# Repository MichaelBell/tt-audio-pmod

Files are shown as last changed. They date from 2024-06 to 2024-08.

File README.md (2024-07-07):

# Tiny Tapeout Audio Pmod

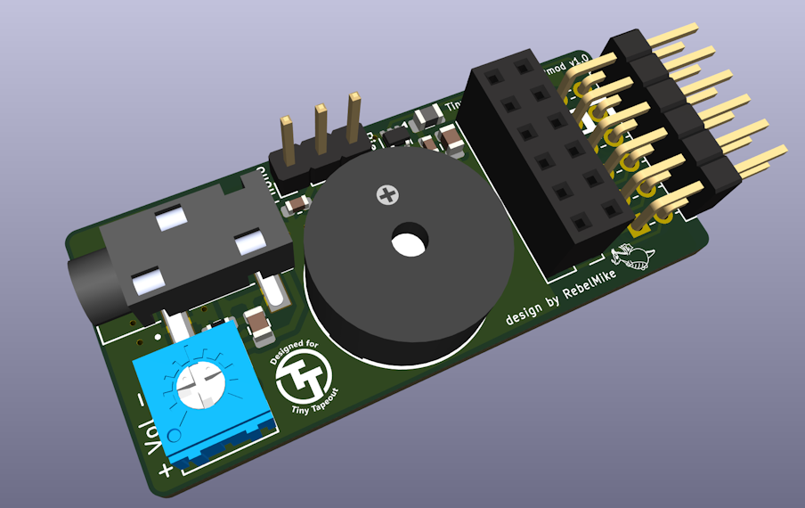
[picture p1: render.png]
Render of the Audio Pmod


This Pmod is designed to play mono PWM audio from out[7] or bidir[7], while allowing a second Pmod to be plugged in, passing through bidir[0-6] or out[0-6].  

The design has a low pass filter, to allow a large range of audio to be played the cutoff frequency is quite high.  It is therefore recommended that the PWM frequency is at least 200kHz to get good results.

If the piezo is selected with the jumper, it is driven after the low pass filter with no further filtering.

If the headphone jack is selected, AC coupling is applied to give a balanced signal.

The volume trim pot should be turned down to around 30-35 ohms to give nominal line level when the output is connected to a high impedance line in.  If using headphones with a low impedance it should be turned up towards the high end of the range (180-200 ohms).

IO 7 on the second Pmod is pulled high, which allows compatibility with the [QSPI Pmod](https://github.com/mole99/qspi-pmod).

The Pmod was designed in KiCad 8, here is the [schematic](tt-audio-pmod.pdf).

## Example Tiny Tapeout project

This [example project](https://github.com/MichaelBell/tt08-pwm-example) generates a PWM output sampling a sine wave of a configurable frequency.

## Simulation

The frequency response of the design was simulated in ltspice:

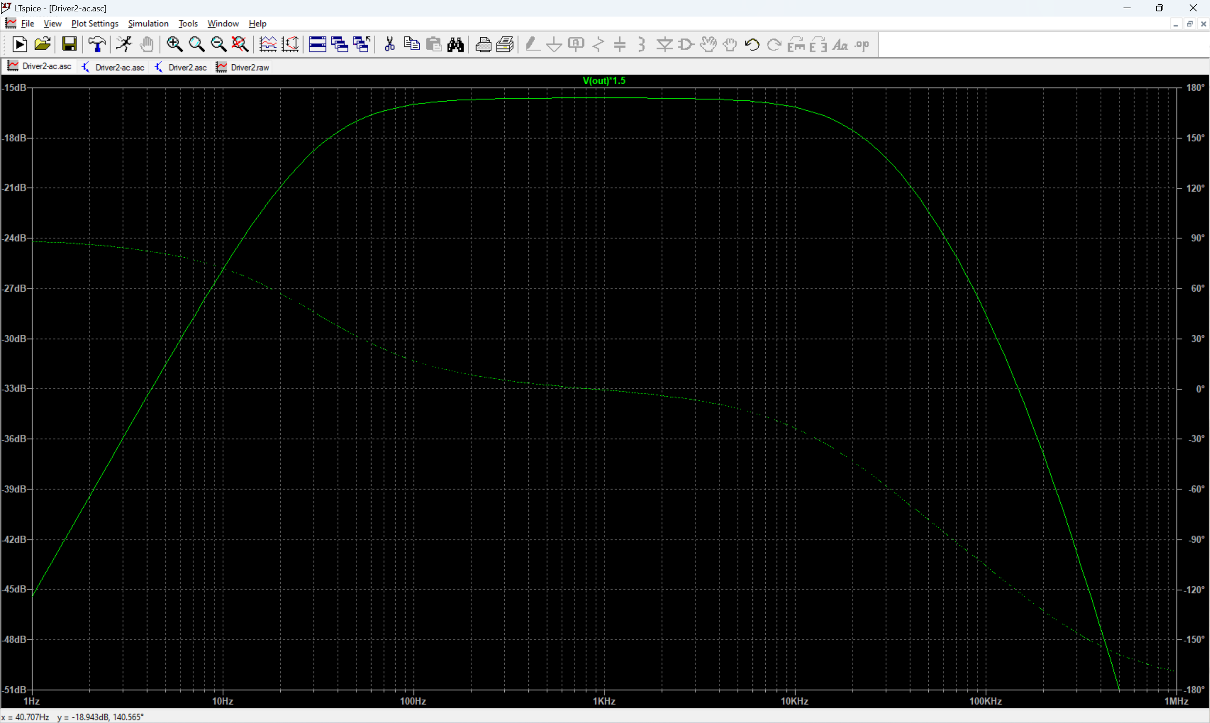
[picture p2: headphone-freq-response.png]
Frequency response with 17 ohm headphones


The ltspice simulations are in the [sim](sim/) directory.

## Testing

The first version of the Pmod is being manufactured and will be tested soon.

## Credits

Designed for Tiny Tapeout by RebelMike with the help of the excellent Tiny Tapeout Discord community.

   Copyright 2024 Mike Bell

   Licensed under the Apache License, Version 2.0 (the "License");
   you may not use this file except in compliance with the License.
   You may obtain a copy of the License at

   http://www.apache.org/licenses/LICENSE-2.0

   Unless required by applicable law or agreed to in writing, software
   distributed under the License is distributed on an "AS IS" BASIS,
   WITHOUT WARRANTIES OR CONDITIONS OF ANY KIND, either express or implied.
   See the License for the specific language governing permissions and
   limitations under the License.

Image on the reverse is by [ArtRose on Pixabay](https://pixabay.com/vectors/musical-notes-music-smile-merry-6159007/).  Used under the [Pixabay Content License](https://pixabay.com/service/license-summary/)

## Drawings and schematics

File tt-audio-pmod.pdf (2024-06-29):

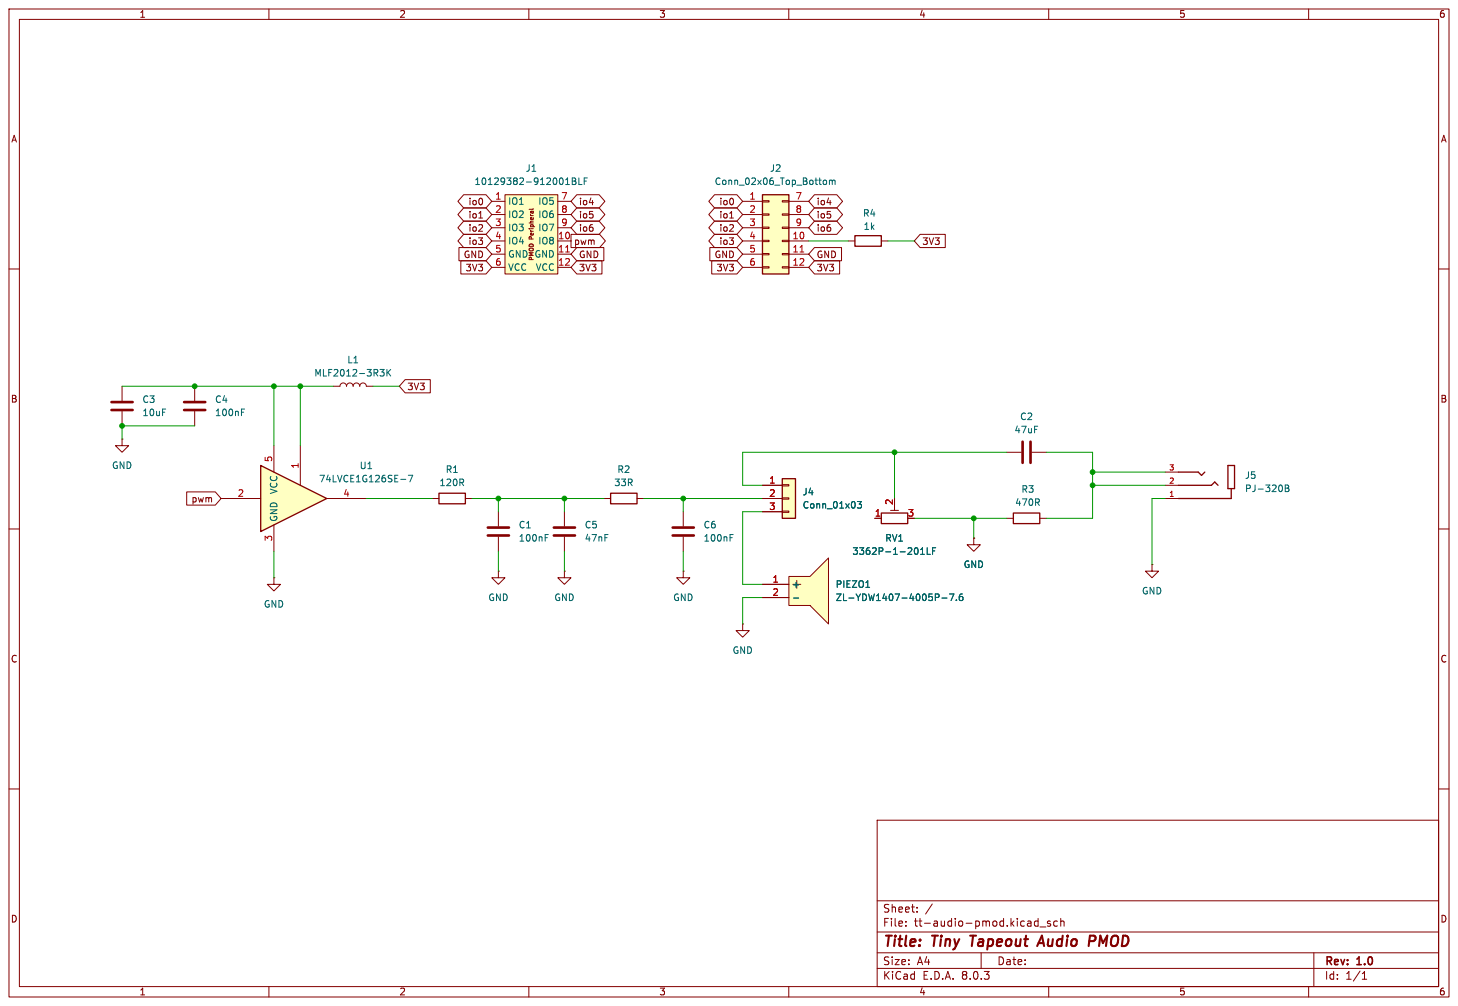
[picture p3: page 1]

File: tt-audio-pmod.kicad_sch Sheet: /
Id: 1/1 Title: Tiny Tapeout Audio PMOD

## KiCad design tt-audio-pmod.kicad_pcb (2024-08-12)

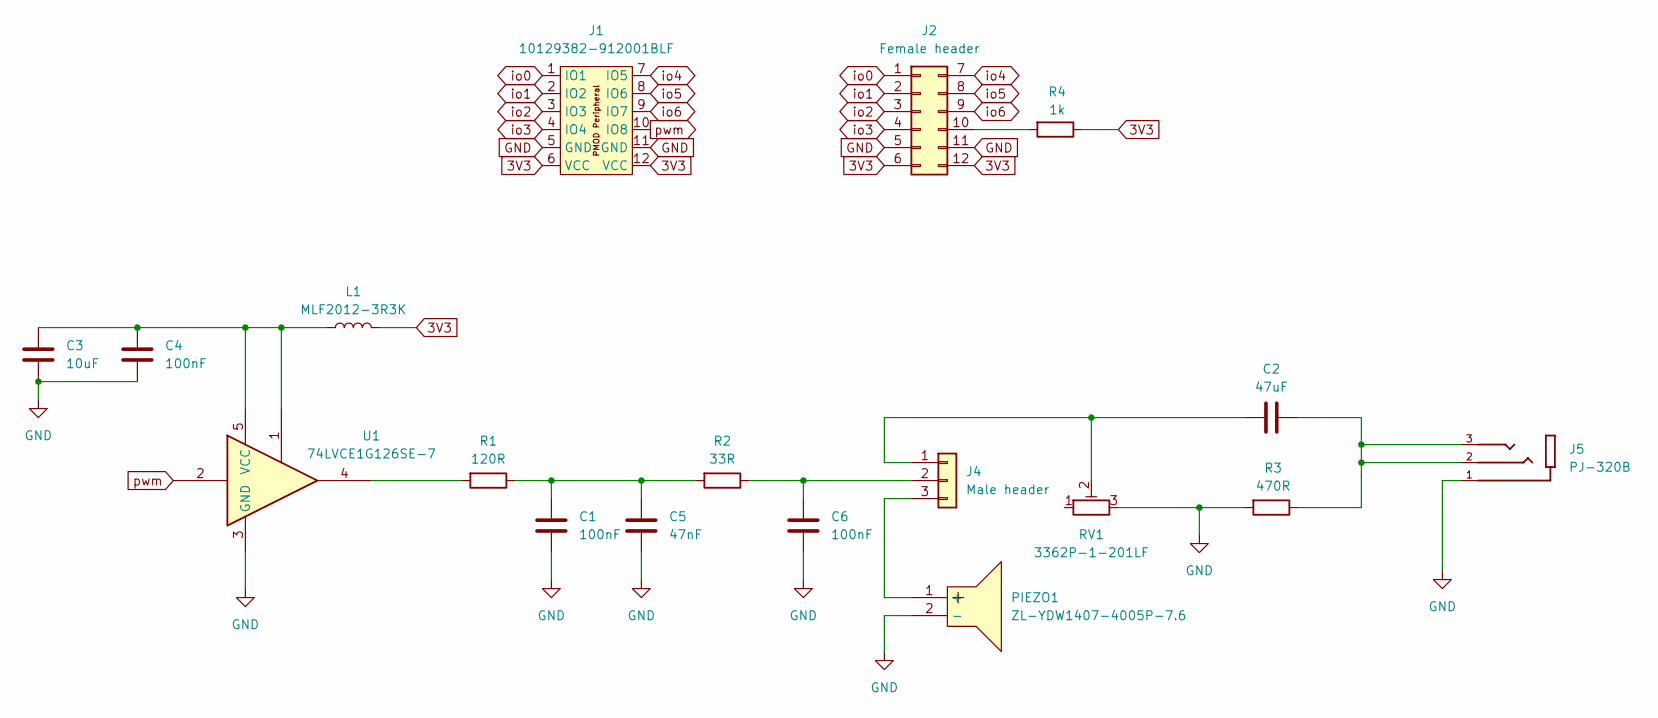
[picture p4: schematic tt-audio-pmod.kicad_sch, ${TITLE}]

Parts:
C1, C4, C6: 100nF; C_0603_1608Metric; LCSC Part C14663
C2: 47uF; C_0805_2012Metric; LCSC Part C16780
C3: 10uF; C_0805_2012Metric; LCSC Part C15850
C5: 47nF; C_0603_1608Metric; LCSC Part C1622
J1: 10129382-912001BLF; PinHeader_2x06_P2.54mm_PMODPeriph2B; LCSC Part C60565
J2: Female header; PinSocket_2x06_P2.54mm_Vertical_Column; LCSC Part C92269
J4: Male header; PinHeader_1x03_P2.54mm_Vertical; LCSC Part C49257
J5: PJ-320B; BOOMELE_PJ-320B; LCSC Part C2884998
L1: MLF2012-3R3K; L_0805_2012Metric; LCSC Part C2941578
PIEZO1: ZL-YDW1407-4005P-7.6; BUZ-TH_BD14.0-P7.60-D0.7-FD; LCSC Part C219740
R1: 120R; R_0603_1608Metric; LCSC Part C22787
R2: 33R; R_0603_1608Metric; LCSC Part C23140
R3: 470R; R_0603_1608Metric; LCSC Part C23179
R4: 1k; R_0603_1608Metric; LCSC Part C21190
RV1: 3362P-1-201LF; TRIM_3362P-1-102; LCSC Part C124581
U1: 74LVCE1G126SE-7; SOT-353_SC-70-5; LCSC Part C842506

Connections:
3V3: J1.6 (VCC), J1.12 (VCC), J2.6, J2.12, L1.2, R4.1
GND: C1.2, C3.2, C4.2, C5.2, C6.2, J1.5 (GND), J1.11 (GND), J2.5, J2.11, J5.1, PIEZO1.2 (-), R3.2, RV1.3, U1.3 (GND)
unnamed: C1.1, C5.1, R1.1, R2.2
unnamed: C2.1, J5.2, J5.3, R3.1
unnamed: J2.10, R4.2
unnamed: C2.2, J4.1, RV1.2
unnamed: C6.1, J4.2, R2.1
unnamed: J4.3, PIEZO1.1 (+)
unnamed: R1.2, U1.4
unnamed: C3.1, C4.1, L1.1, U1.1, U1.5 (VCC)
io0: J1.1 (IO1), J2.1
io1: J1.2 (IO2), J2.2
io2: J1.3 (IO3), J2.3
io3: J1.4 (IO4), J2.4
io4: J1.7 (IO5), J2.7
io5: J1.8 (IO6), J2.8
io6: J1.9 (IO7), J2.9
pwm: J1.10 (IO8), U1.2

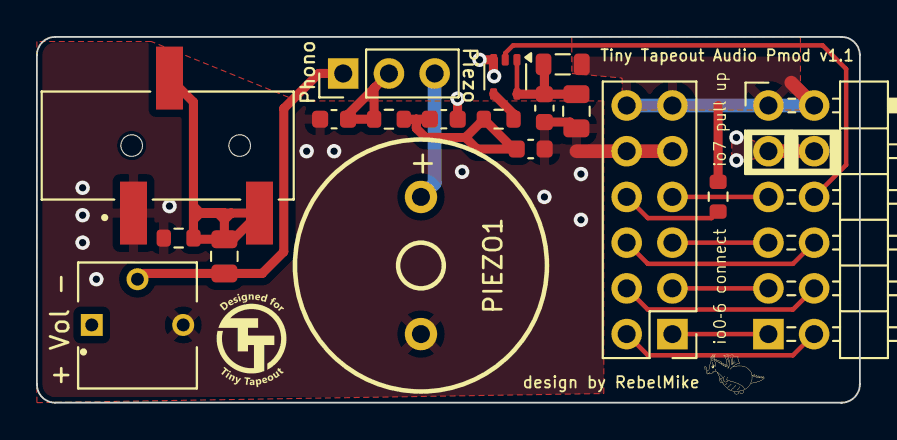
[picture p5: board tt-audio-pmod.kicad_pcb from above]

Board: 2 copper layers, 45.7 x 20.3 mm, 18 parts (0 on the bottom side), 18 nets.

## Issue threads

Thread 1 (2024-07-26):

Please add the jlcpcb cam files once you're doing testing

TomKeddie, 2024-07-26:
Hi Michael, thanks for doing this pmod.

This is more a reminder than an issue.  I wanted to get a board done, please add the cam files to the repo (or as a release) when you're done testing.

Thanks,
Tom

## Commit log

2024-06-30 Change board shape
    [tt-audio-pmod.kicad_pcb]
2024-07-01 Minor tweaks
    [tt-audio-pmod.kicad_pcb]
2024-07-02 Improve ground coherence and thermal relief
    [tt-audio-pmod.kicad_pcb]
2024-07-02 Add art
    [tt-audio-pmod.kicad_pcb]
2024-07-02 Version 1.0 as sent to JLCPCB
    [jlcpcb-bom.xls, tt-audio-pmod.kicad_pcb]
2024-08-12 Silkscreen and BOM updates
    [tt-audio-pmod.kicad_pcb, tt-audio-pmod.kicad_sch]
2024-08-12 Remove BOM, instead it will be in release
    [jlcpcb-bom.xls]
